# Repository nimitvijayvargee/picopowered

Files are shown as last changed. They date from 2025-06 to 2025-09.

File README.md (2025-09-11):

# picopowered
A simple microcontroller built around the RP2040.

# Changelog (V3)
- Redesigned board layout
- Doubled headers
- Dip switches and SD card slot connected to GP13-15 and GP16-19+29 respectively
- Better power system and circuit design

# Changelog (V2)
- Replaced 2020 Neopixel with more available 5050 footprint.
- Fixed seperation between 1v1 and 3v3 power planes.
- Better positioning and tracing of the components to improve overall signal integrity.
- Added a regular LED to keep it somewhat compatible with regular Pico SDK Code.
- Modified USB C port to be THT Mounted rather than completely SMD.
- Moved GPIO 29 from VSYS Sense to an exposed pad on the bottom side of the PCB.

# Featureset
| **Stat** | **Raspberry Pi Pico 1** | **Picopowered V1-RP2040** |
|---|---|---|
| Flash | 2MB | 16MB |
| Reset Button | No | Yes |
| LED | Yes (1 Color) | Yes (RGB Neopixel) |
| User GPIO Button | No | Yes |
| USB Type | Micro-B | C |

# Disadvantages
- Linear regulator requuires minimum of 3.3 Volts, unlike Pico's buck boost converter which can be powered by 1.8 Volts.
- ~~No ADC_VREF (connected to GND instead) because the power by linear regulator is filtered already.~~ ADC VREF now works with picopowered V2 and V3
- No Power Mode selection (stems from power supply used)

Most of the disadvantages occur only due to the Pico's superior power supply system, but the system on the PicoPowered board is more filtered and smooth.

# BOM
| **Part** | **Cost (USD)** |
|---|---|
| PCB + Assembly | 120 |
| Solder Wire | 3 |
| Headers | 3 |

For parts specific BOM, check picopowered.csv in /Production/

# Gallery
## V3 (Latest)
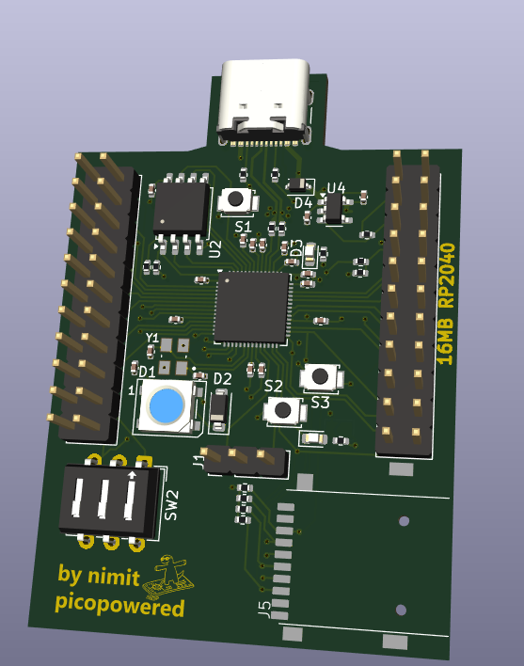
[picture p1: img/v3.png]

## V2
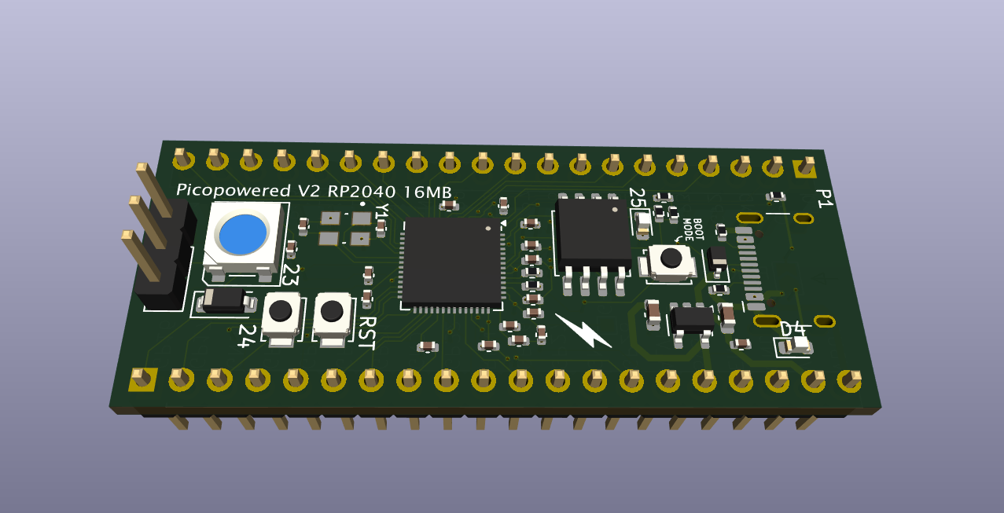
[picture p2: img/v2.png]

## V1
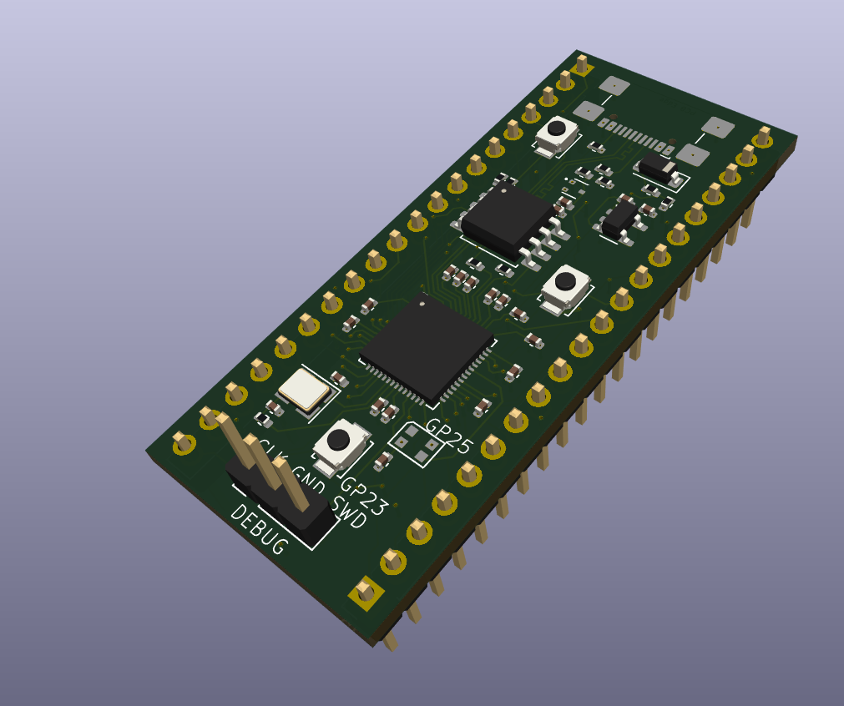
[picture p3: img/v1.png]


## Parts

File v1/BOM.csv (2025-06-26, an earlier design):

Part | Cost (USD)
PCB + Assembly | 120
Solder Wire | 3
Headers | 3
Total | 3

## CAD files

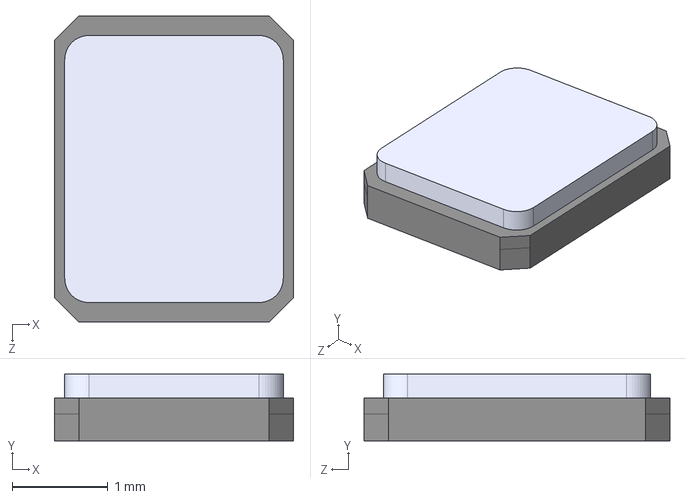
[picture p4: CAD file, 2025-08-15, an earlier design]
v2/kicad-lib/ABM8-272-T3.step
2.50 x 0.7 x 3.20 mm

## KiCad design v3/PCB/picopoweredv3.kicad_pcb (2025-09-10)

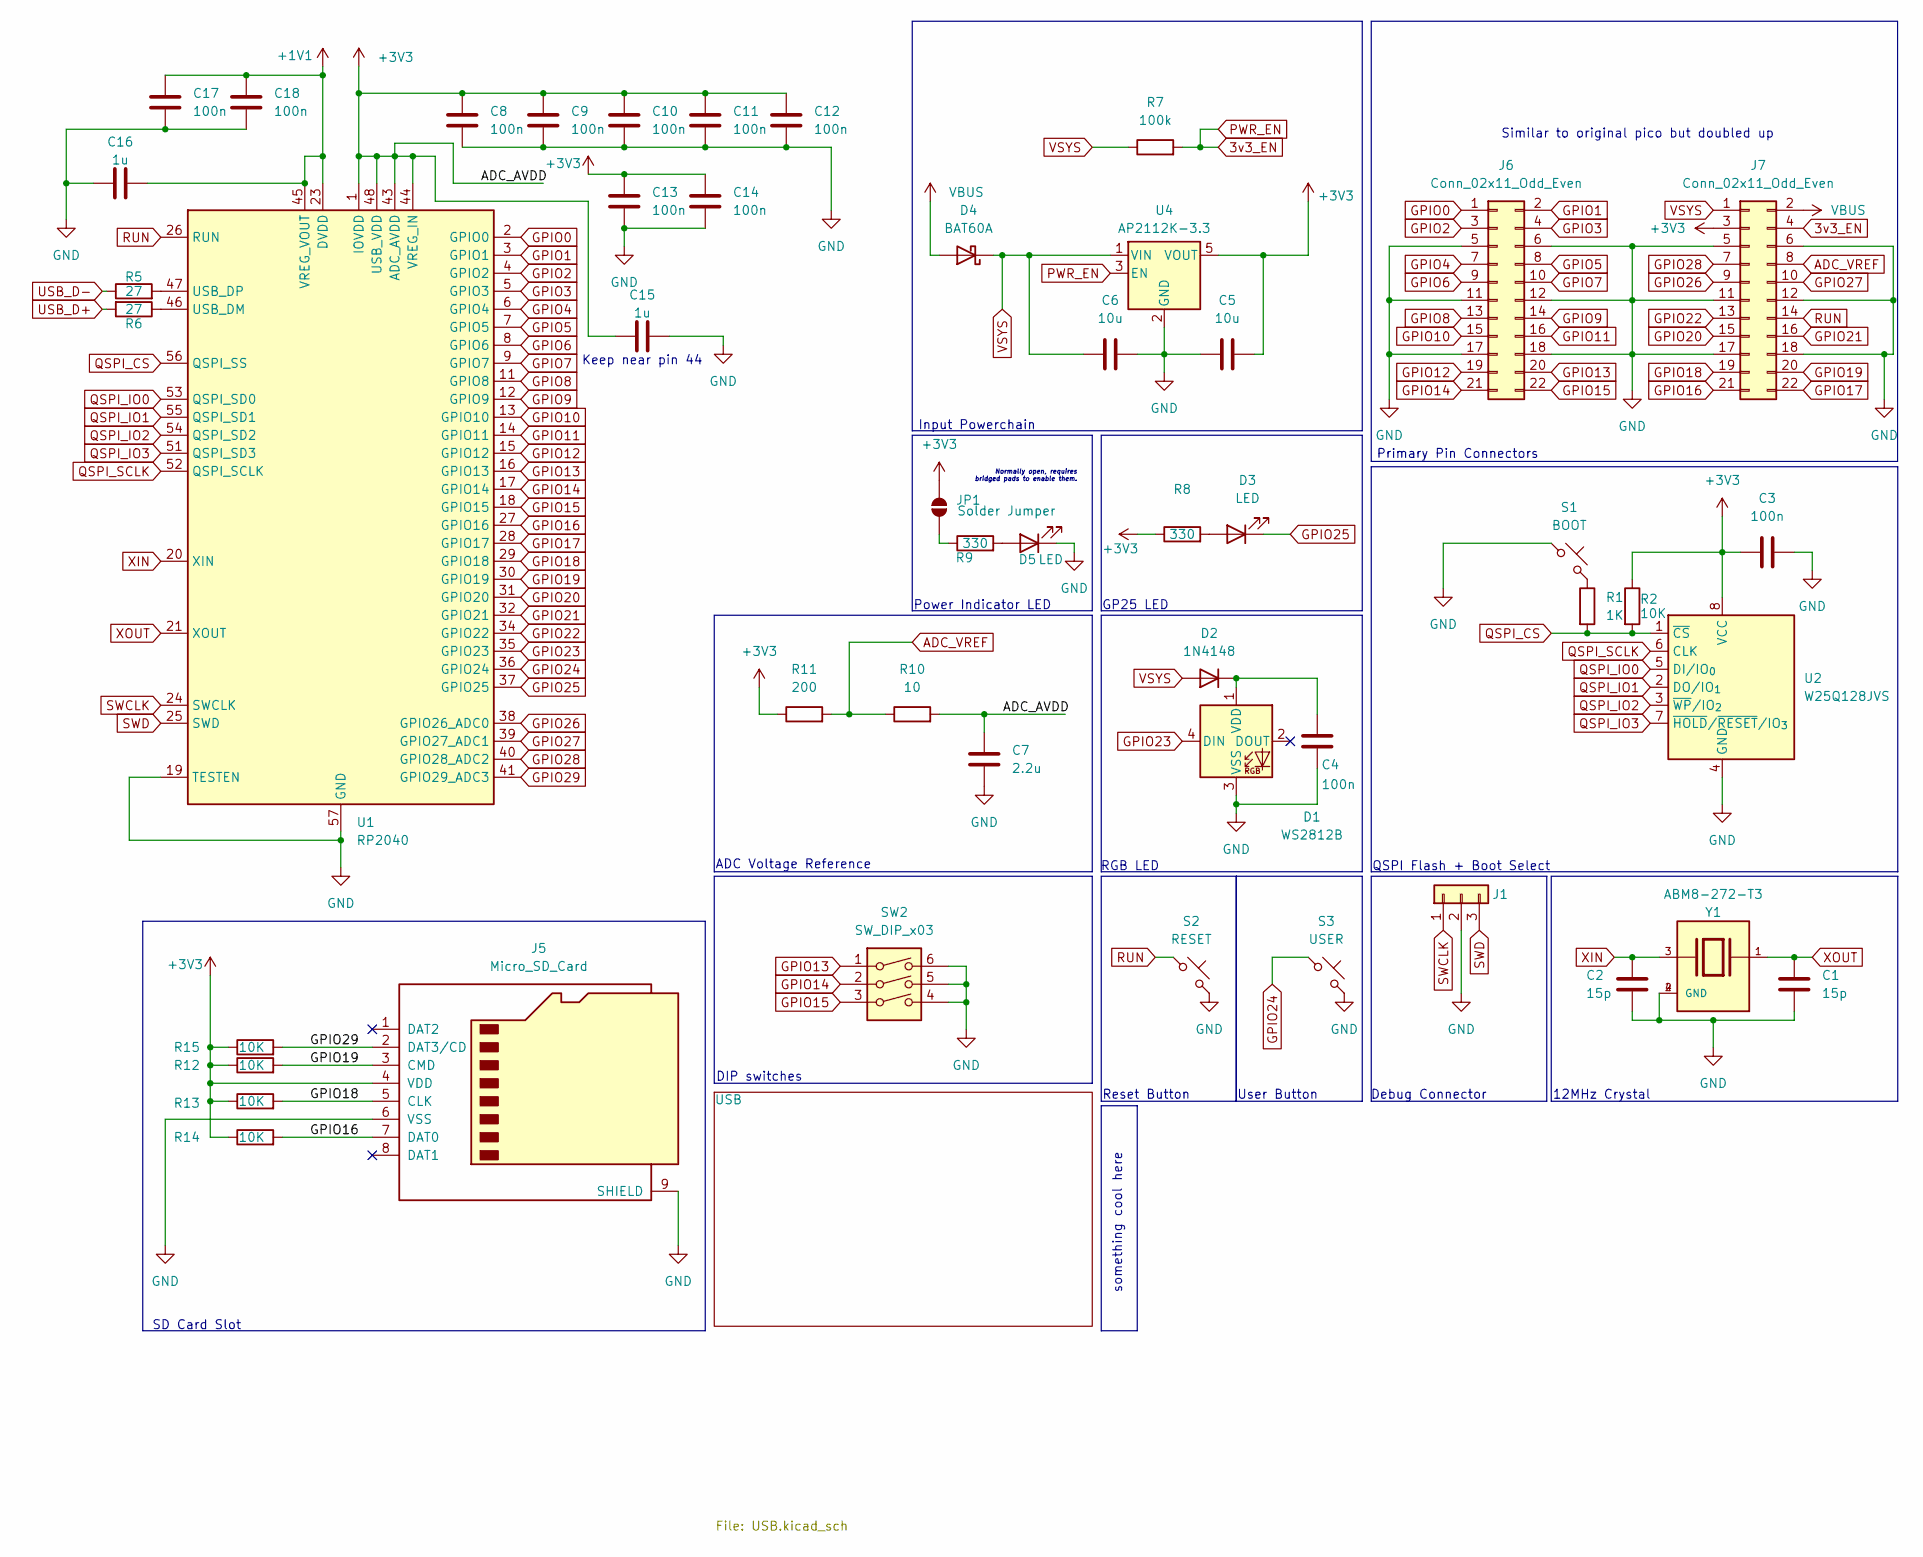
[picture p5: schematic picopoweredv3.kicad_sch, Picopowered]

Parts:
C1, C2: 15p; C_0402_1005Metric
C3, C4, C8, C9, C10, C11, C12, C13, C14, C17, C18: 100n; C_0402_1005Metric
C5, C6: 10u; C_0402_1005Metric
C7: 2.2u; C_0402_1005Metric
C15, C16: 1u; C_0402_1005Metric
D1: WS2812B; LED_WS2812B_PLCC4_5.0x5.0mm_P3.2mm
D2: 1N4148; D_SOD-123
D3, D5: LED; LED_0603_1608Metric
D4: BAT60A; D_SOD-323
J1: Conn_01x03; PinHeader_1x03_P2.54mm_Vertical
J5: Micro_SD_Card; Micro_SD_READER
J6, J7: Conn_02x11_Odd_Even; PinHeader_2x11_P2.54mm_Vertical
JP1: Solder Jumper; SolderJumper-2_P1.3mm_Open_TrianglePad1.0x1.5mm
R1: 1K; R_0402_1005Metric
R2, R12, R13, R14, R15: 10K; R_0402_1005Metric
R5, R6: 27; R_0402_1005Metric
R7: 100k; R_0402_1005Metric
R8, R9: 330; R_0402_1005Metric
R10: 10; R_0402_1005Metric
R11: 200; R_0402_1005Metric
S1: BOOT; SW_SPST_B3U-1000P
S2: RESET; SW_SPST_B3U-1000P
S3: USER; SW_SPST_B3U-1000P
SW2: SW_DIP_x03; SW_DIP_SPSTx03_Slide_6.7x9.18mm_W7.62mm_P2.54mm_LowProfile
U1: RP2040; QFN-56-1EP_7x7mm_P0.4mm_EP3.2x3.2mm
U2: W25Q128JVS; SOIC-8_5.3x5.3mm_P1.27mm
U4: AP2112K-3.3; SOT-23-5
Y1: ABM8-272-T3; XTAL_ABM8-272-T3; PARTREV 07-29-20

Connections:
3v3_EN: J7.4, R7.2, U4.3 (EN)
+1V1: C16.1, C17.1, C18.1, U1.23 (DVDD), U1.45 (VREG_VOUT), U1.50 (DVDD)
+3V3: C3.1, C5.1, C7.1, C8.1, C9.1, C10.1, C11.1, C12.1, C13.1, C14.1, C15.1, J5.4 (VDD), J7.3, JP1.2 (B), R2.1, R8.1, R10.2, R11.1, R12.1, R13.1, R14.1, R15.1, U1.1 (IOVDD), U1.10 (IOVDD), U1.22 (IOVDD), U1.33 (IOVDD), U1.42 (IOVDD), U1.43 (ADC_AVDD), U1.44 (VREG_IN), U1.48 (USB_VDD), U1.49 (IOVDD), U2.8 (VCC), U4.5 (VOUT)
ADC_VREF: J7.8, R10.1, R11.2
GND: C1.2, C2.2, C3.2, C4.1, C5.2, C6.2, C7.2, C8.2, C9.2, C10.2, C11.2, C12.2, C13.2, C14.2, C15.2, C16.2, C17.2, C18.2, D1.3 (VSS), D5.1 (K), J1.2, J5.6 (VSS), J5.9 (SHIELD), J6.5, J6.6, J6.11, J6.12, J6.17, J6.18, J7.5, J7.6, J7.11, J7.12, J7.17, J7.18, S1.1, S2.2, S3.2, SW2.4, SW2.5, SW2.6, U1.19 (TESTEN), U1.57 (GND), U2.4 (GND), U4.2 (GND), Y1.2 (GND), Y1.4 (GND); also elsewhere on the board
GPIO0: J6.1, U1.2 (GPIO0)
GPIO1: J6.2, U1.3 (GPIO1)
GPIO2: J6.3, U1.4 (GPIO2)
GPIO3: J6.4, U1.5 (GPIO3)
GPIO4: J6.7, U1.6 (GPIO4)
GPIO5: J6.8, U1.7 (GPIO5)
GPIO6: J6.9, U1.8 (GPIO6)
GPIO7: J6.10, U1.9 (GPIO7)
GPIO8: J6.13, U1.11 (GPIO8)
GPIO9: J6.14, U1.12 (GPIO9)
GPIO10: J6.15, U1.13 (GPIO10)
GPIO11: J6.16, U1.14 (GPIO11)
GPIO12: J6.19, U1.15 (GPIO12)
GPIO13: J6.20, SW2.1, U1.16 (GPIO13)
GPIO14: J6.21, SW2.2, U1.17 (GPIO14)
GPIO15: J6.22, SW2.3, U1.18 (GPIO15)
GPIO16: J5.7 (DAT0), J7.21, R14.2, U1.27 (GPIO16)
GPIO17: J7.22, U1.28 (GPIO17)
GPIO18: J5.5 (CLK), J7.19, R13.2, U1.29 (GPIO18)
GPIO19: J5.3 (CMD), J7.20, R12.2, U1.30 (GPIO19)
GPIO20: J7.15, U1.31 (GPIO20)
GPIO21: J7.16, U1.32 (GPIO21)
GPIO22: J7.13, U1.34 (GPIO22)
GPIO23: D1.4 (DIN), U1.35 (GPIO23)
GPIO24: S3.1, U1.36 (GPIO24)
GPIO25: D3.1 (K), U1.37 (GPIO25)
GPIO26: J7.9, U1.38 (GPIO26_ADC0)
GPIO27: J7.10, U1.39 (GPIO27_ADC1)
GPIO28: J7.7, U1.40 (GPIO28_ADC2)
GPIO29: J5.2 (DAT3/CD), R15.2, U1.41 (GPIO29_ADC3)
unnamed: C4.2, D1.1 (VDD), D2.1 (K)
unnamed: D3.2 (A), R8.2
unnamed: D5.2 (A), R9.2
unnamed: JP1.1 (A), R9.1
unnamed: R1.1, S1.2
unnamed: R6.1, U1.46 (USB_DM)
unnamed: R5.2, U1.47 (USB_DP)
QSPI_CS: R1.2, R2.2, U1.56 (QSPI_SS), U2.1 (~CS)
QSPI_IO0: U1.53 (QSPI_SD0), U2.5 (DI/IO_{0})
QSPI_IO1: U1.55 (QSPI_SD1), U2.2 (DO/IO_{1})
QSPI_IO2: U1.54 (QSPI_SD2), U2.3 (~WP/IO_{2})
QSPI_IO3: U1.51 (QSPI_SD3), U2.7 (~HOLD/~RESET/IO_{3})
QSPI_SCLK: U1.52 (QSPI_SCLK), U2.6 (CLK)
RUN: J7.14, S2.1, U1.26 (RUN)
SWCLK: J1.1, U1.24 (SWCLK)
SWD: J1.3, U1.25 (SWD)
USB_D+: R6.2; also elsewhere on the board
USB_D-: R5.1; also elsewhere on the board
VBUS: D4.2 (A), J7.2; also elsewhere on the board
VSYS: C6.1, D2.2 (A), D4.1 (K), J7.1, R7.1, U4.1 (VIN)
XIN: C2.1, U1.20 (XIN), Y1.3
XOUT: C1.1, U1.21 (XOUT), Y1.1

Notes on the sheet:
Similar to original pico but doubled up
DIP switches
ADC Voltage Reference
Normally open, requires bridged pads to enable them.
GP25 LED
User Button
QSPI Flash + Boot Select
Primary Pin Connectors
something cool here
RGB LED
Input Powerchain
Debug Connector
12MHz Crystal
Keep near pin 44
SD Card Slot
Power Indicator LED
Reset Button

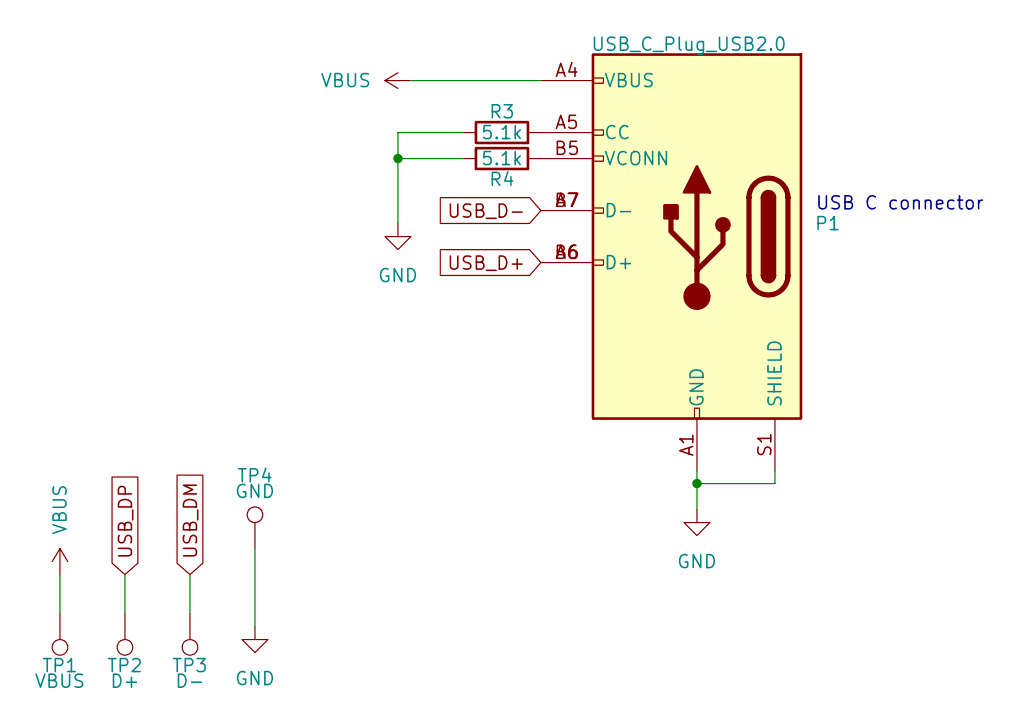
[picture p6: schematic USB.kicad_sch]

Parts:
P1: USB_C_Plug_USB2.0; USB_C_Receptacle_GCT_USB4105-xx-A_16P_TopMnt_Horizontal
R3, R4: 5.1k; R_0402_1005Metric
TP1: VBUS; TestPoint_Pad_1.0x1.0mm
TP2: D+; TestPoint_Pad_1.0x1.0mm
TP3: D-; TestPoint_Pad_1.0x1.0mm
TP4: GND; TestPoint_Pad_1.0x1.0mm

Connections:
GND: P1.A1 (GND), P1.A12 (GND), P1.B1 (GND), P1.B12 (GND), P1.S1 (SHIELD), R3.1, R4.1, TP4.1; also elsewhere on the board
unnamed: P1.A5 (CC), R3.2
unnamed: P1.B5 (VCONN), R4.2
USB_D+: P1.A6 (D+), P1.B6 (D+); also elsewhere on the board
USB_D-: P1.A7 (D-), P1.B7 (D-); also elsewhere on the board
VBUS: P1.A4 (VBUS), P1.A9 (VBUS), P1.B4 (VBUS), P1.B9 (VBUS), TP1.1; also elsewhere on the board

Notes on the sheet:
USB C connector

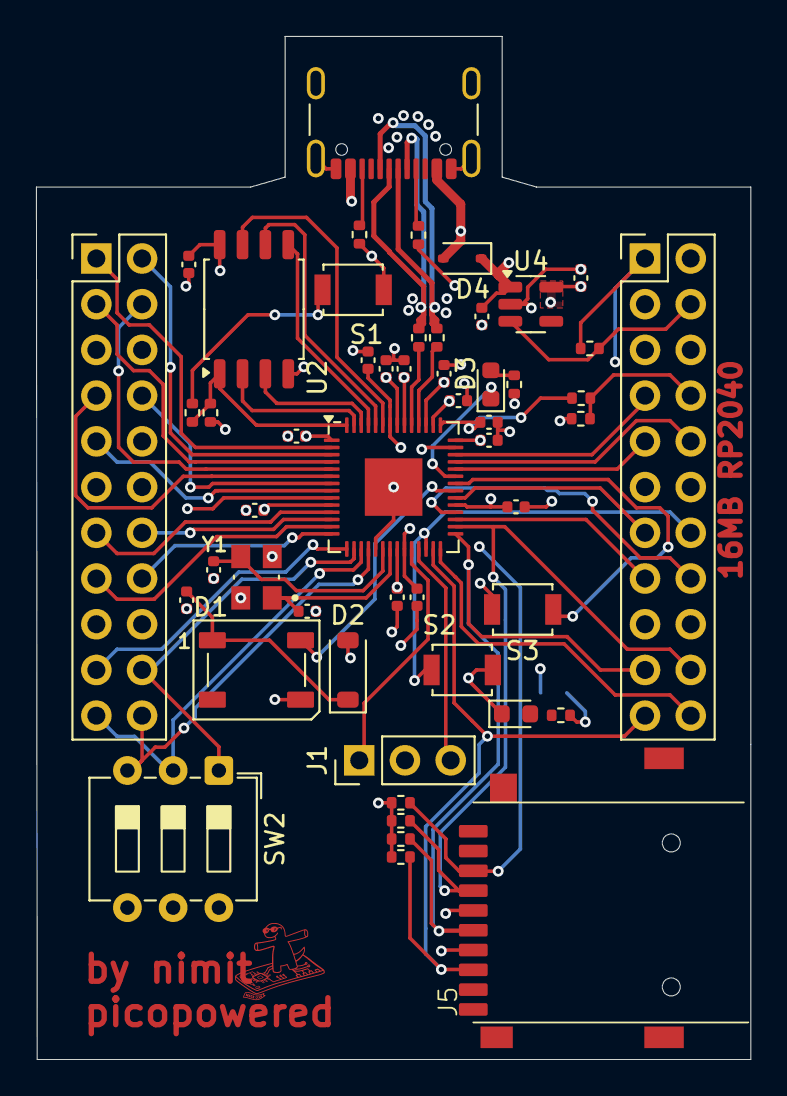
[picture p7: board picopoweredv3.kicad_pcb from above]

Board: 4 copper layers, 39.7 x 56.8 mm, 52 parts (1 on the bottom side), 59 nets.

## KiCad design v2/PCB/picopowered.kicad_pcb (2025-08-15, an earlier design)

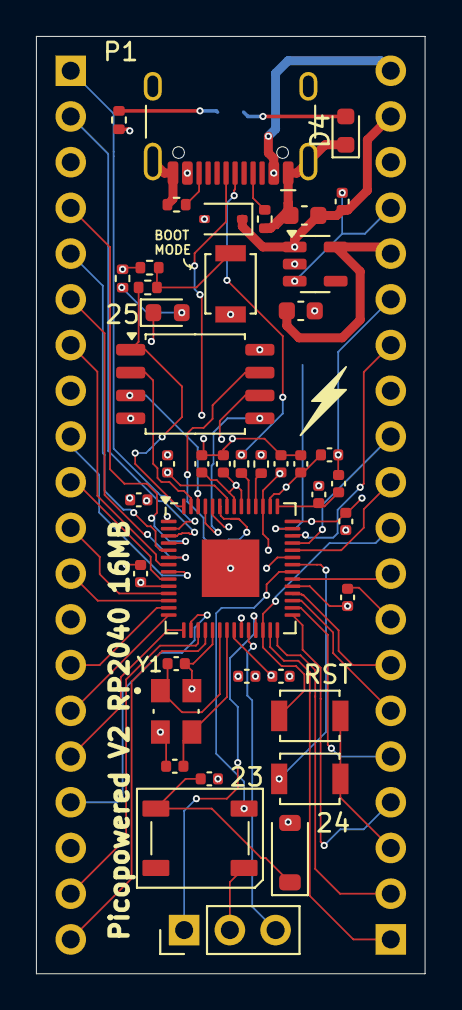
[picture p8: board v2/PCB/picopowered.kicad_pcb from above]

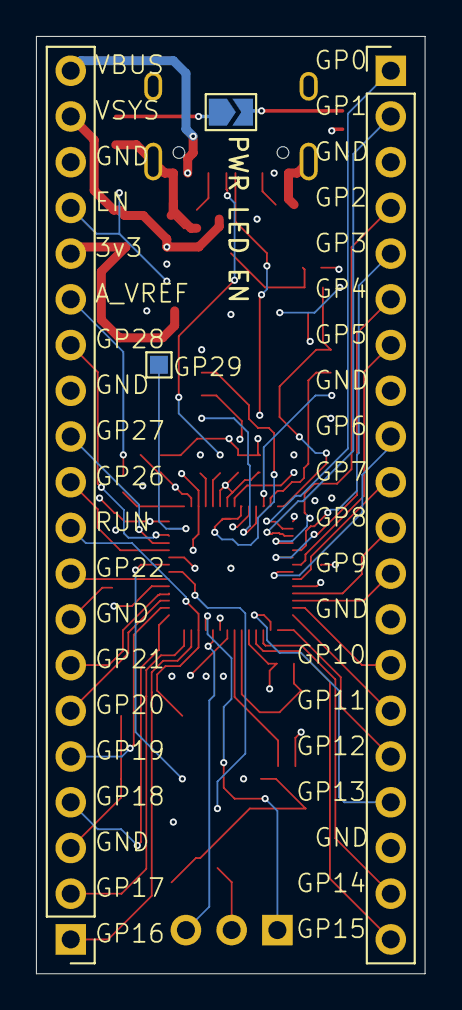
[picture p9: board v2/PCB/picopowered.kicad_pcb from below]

Board: 4 copper layers, 21.6 x 52.1 mm, 46 parts (4 on the bottom side), 60 nets.

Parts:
24: USER_BUTTON; SW_SPST_B3U-1000P
25: LED; LED_0603_1608Metric
BOOT: BOOT_SELECT; SW_SPST_B3U-1000P
C1, C2: 15p; C_0402_1005Metric
C3, C4, C5, C6, C7, C8, C9, C10, C10#2, C13: 100n; C_0402_1005Metric
C11, C12, C16: 2.2u; C_0402_1005Metric
C14: 10u; C_0603_1608Metric
C15: 22u; C_0603_1608Metric
D1: WS2812B; LED_WS2812B_PLCC4_5.0x5.0mm_P3.2mm
D2: 1N4148; D_SOD-123
D4: LED; LED_0603_1608Metric
D5: BAT60A; D_SOD-323
J1: Conn_01x03; PinHeader_1x03_P2.54mm_Vertical
J2, J3: Conn_01x20; PinHeader_1x20_P2.54mm_Vertical
P1: USB_C_Plug_USB2.0; USB_C_Receptacle_HCTL_HC-TYPE-C-16P-01A
PWR LED EN: SolderJumper_2_Open; SolderJumper-2_P1.3mm_Open_TrianglePad1.0x1.5mm
Picopowered V2 RP2040 16MB: RP2040; QFN-56-1EP_7x7mm_P0.4mm_EP3.2x3.2mm
R1, R2: 27; R_0402_1005Metric
R3: 1k; R_0402_1005Metric
R4: 10k; R_0402_1005Metric
R5, R6: 5.1k; R_0402_1005Metric
R7, R8: 330; R_0402_1005Metric
R9: 10; C_0402_1005Metric
R10: 200; C_0402_1005Metric
R11: 100K; C_0402_1005Metric
RST: Keyswitch; SW_SPST_B3U-1000P
TP1: GP29; TestPoint_Pad_1.0x1.0mm
U2: W25Q128JVS; SOIC-8_5.3x5.3mm_P1.27mm
U4: AP2112K-3.3; SOT-23-5
Y1: ABM8-272-T3; XTAL_ABM8-272-T3

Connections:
3v3_EN: J3.17, R11.1, U4.3 (EN)
+1V1: C3.1, C4.1, C12.1, Picopowered V2 RP2040 16MB.23 (DVDD), Picopowered V2 RP2040 16MB.45 (VREG_VOUT), Picopowered V2 RP2040 16MB.50 (DVDD)
+3V3: C5.1, C6.1, C7.1, C8.1, C9.1, C10.1, C10#2.1, C11.1, C15.2, J3.16, Picopowered V2 RP2040 16MB.1 (IOVDD), Picopowered V2 RP2040 16MB.10 (IOVDD), Picopowered V2 RP2040 16MB.22 (IOVDD), Picopowered V2 RP2040 16MB.33 (IOVDD), Picopowered V2 RP2040 16MB.42 (IOVDD), Picopowered V2 RP2040 16MB.44 (VREG_IN), Picopowered V2 RP2040 16MB.48 (USB_VDD), Picopowered V2 RP2040 16MB.49 (IOVDD), R4.2, R7.2, R8.2, R10.1, U2.8 (VCC), U4.5 (VOUT)
ADC_AVDD: C16.1, Picopowered V2 RP2040 16MB.43 (ADC_AVDD), R9.2
ADC_VREF: J3.15, R9.1, R10.2
GND: 24.2, BOOT.1, C1.1, C2.1, C3.2, C4.2, C5.2, C6.2, C7.2, C8.2, C9.2, C10.2, C10#2.2, C11.2, C12.2, C13.2, C14.1, C15.1, C16.2, D1.3 (VSS), D4.1 (K), J1.2, J2.3, J2.8, J2.13, J2.18, J3.3, J3.8, J3.13, J3.18, P1.A1 (GND), P1.A12 (GND), P1.B1 (GND), P1.B12 (GND), P1.S1 (SHIELD), Picopowered V2 RP2040 16MB.19 (TESTEN), Picopowered V2 RP2040 16MB.57 (GND), R5.2, R6.2, RST.2, U2.4 (GND), U4.2 (GND), Y1.2 (GND), Y1.4 (GND)
GPIO0: J2.1, Picopowered V2 RP2040 16MB.2 (GPIO0)
GPIO1: J2.2, Picopowered V2 RP2040 16MB.3 (GPIO1)
GPIO2: J2.4, Picopowered V2 RP2040 16MB.4 (GPIO2)
GPIO3: J2.5, Picopowered V2 RP2040 16MB.5 (GPIO3)
GPIO4: J2.6, Picopowered V2 RP2040 16MB.6 (GPIO4)
GPIO5: J2.7, Picopowered V2 RP2040 16MB.7 (GPIO5)
GPIO6: J2.9, Picopowered V2 RP2040 16MB.8 (GPIO6)
GPIO7: J2.10, Picopowered V2 RP2040 16MB.9 (GPIO7)
GPIO8: J2.11, Picopowered V2 RP2040 16MB.11 (GPIO8)
GPIO9: J2.12, Picopowered V2 RP2040 16MB.12 (GPIO9)
GPIO10: J2.14, Picopowered V2 RP2040 16MB.13 (GPIO10)
GPIO11: J2.15, Picopowered V2 RP2040 16MB.14 (GPIO11)
GPIO12: J2.16, Picopowered V2 RP2040 16MB.15 (GPIO12)
GPIO13: J2.17, Picopowered V2 RP2040 16MB.16 (GPIO13)
GPIO14: J2.19, Picopowered V2 RP2040 16MB.17 (GPIO14)
GPIO15: J2.20, Picopowered V2 RP2040 16MB.18 (GPIO15)
GPIO16: J3.1, Picopowered V2 RP2040 16MB.27 (GPIO16)
GPIO17: J3.2, Picopowered V2 RP2040 16MB.28 (GPIO17)
GPIO18: J3.4, Picopowered V2 RP2040 16MB.29 (GPIO18)
GPIO19: J3.5, Picopowered V2 RP2040 16MB.30 (GPIO19)
GPIO20: J3.6, Picopowered V2 RP2040 16MB.31 (GPIO20)
GPIO21: J3.7, Picopowered V2 RP2040 16MB.32 (GPIO21)
GPIO22: J3.9, Picopowered V2 RP2040 16MB.34 (GPIO22)
GPIO23: D1.4 (DIN), Picopowered V2 RP2040 16MB.35 (GPIO23)
GPIO24: 24.1, Picopowered V2 RP2040 16MB.36 (GPIO24)
GPIO25: 25.1 (K), Picopowered V2 RP2040 16MB.37 (GPIO25)
GPIO26: J3.11, Picopowered V2 RP2040 16MB.38 (GPIO26_ADC0)
GPIO27: J3.12, Picopowered V2 RP2040 16MB.39 (GPIO27_ADC1)
GPIO28: J3.14, Picopowered V2 RP2040 16MB.40 (GPIO28_ADC2)
GPIO29: Picopowered V2 RP2040 16MB.41 (GPIO29_ADC3), TP1.1
unnamed: C13.1, D1.1 (VDD), D2.1 (K)
unnamed: 25.2 (A), R7.1
unnamed: D4.2 (A), PWR LED EN.1 (A)
unnamed: J1.1, Picopowered V2 RP2040 16MB.25 (SWD)
unnamed: J1.3, Picopowered V2 RP2040 16MB.24 (SWCLK)
unnamed: PWR LED EN.2 (B), R8.1
unnamed: P1.A5 (CC), R5.1
unnamed: P1.B5 (VCONN), R6.1
unnamed: BOOT.2, R3.1, R4.1
unnamed: Picopowered V2 RP2040 16MB.46 (USB_DM), R2.2
unnamed: Picopowered V2 RP2040 16MB.47 (USB_DP), R1.2
unnamed: C1.2, Picopowered V2 RP2040 16MB.20 (XIN), Y1.1
unnamed: C2.2, Picopowered V2 RP2040 16MB.21 (XOUT), Y1.3
QSPI_SCLK: Picopowered V2 RP2040 16MB.52 (QSPI_SCLK), U2.6 (CLK)
QSPI_SD0: Picopowered V2 RP2040 16MB.53 (QSPI_SD0), U2.5 (DI/IO_{0})
QSPI_SD1: Picopowered V2 RP2040 16MB.55 (QSPI_SD1), U2.2 (DO/IO_{1})
QSPI_SD2: Picopowered V2 RP2040 16MB.54 (QSPI_SD2), U2.3 (~WP/IO_{2})
QSPI_SD3: Picopowered V2 RP2040 16MB.51 (QSPI_SD3), U2.7 (~HOLD/~RESET/IO_{3})
QSPI_SS: Picopowered V2 RP2040 16MB.56 (QSPI_SS), R3.2, U2.1 (~CS)
RUN: J3.10, Picopowered V2 RP2040 16MB.26 (RUN), RST.1
USB_D+: P1.A6 (D+), R1.1
USB_D-: P1.A7 (D-), R2.1
VBUS: D5.2 (A), J3.20, P1.A4 (VBUS), P1.A9 (VBUS), P1.B4 (VBUS), P1.B9 (VBUS)
VSYS: C14.2, D2.2 (A), D5.1 (K), J3.19, R11.2, U4.1 (VIN)

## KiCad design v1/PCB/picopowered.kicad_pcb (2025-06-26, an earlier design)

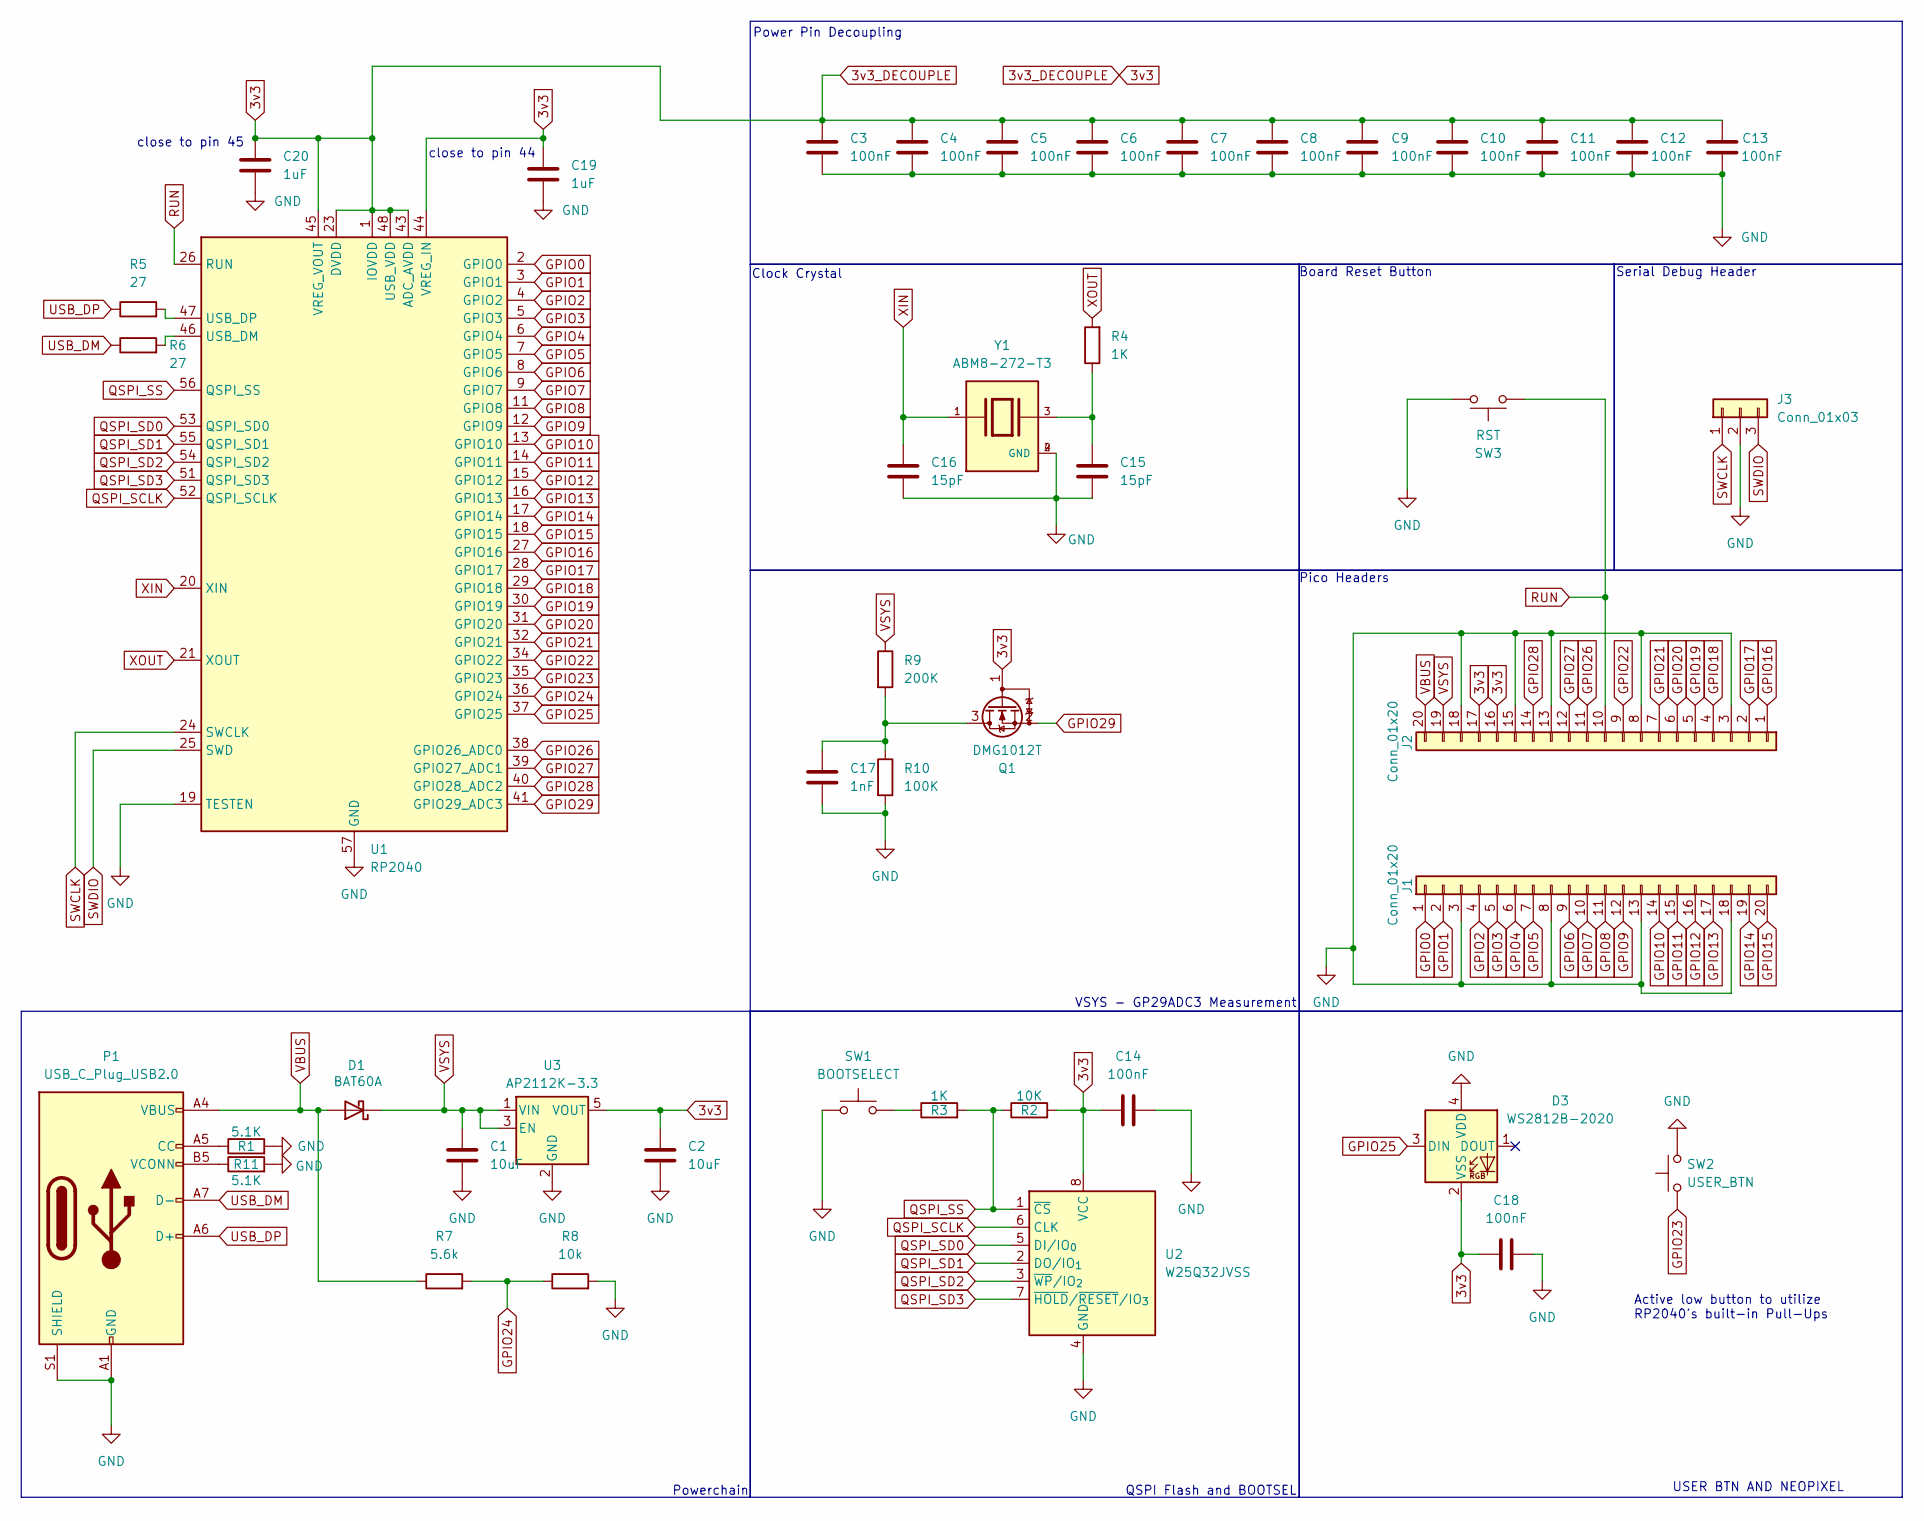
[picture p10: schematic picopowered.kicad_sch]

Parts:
C1, C2: 10uF; C_0402_1005Metric
C3, C4, C5, C6, C7, C8, C9, C10, C11, C12, C13, C14, C18: 100nF; C_0402_1005Metric
C15, C16: 15pF; C_0402_1005Metric
C17: 1nF; C_0402_1005Metric
C19, C20: 1uF; C_0402_1005Metric
D1: BAT60A; D_SOD-123
D3: WS2812B-2020; LED_WS2812B-2020_PLCC4_2.0x2.0mm
J1, J2: Conn_01x20; PinHeader_1x20_P2.54mm_Vertical
J3: Conn_01x03; PinHeader_1x03_P2.54mm_Vertical
P1: USB_C_Plug_USB2.0; USB_C_Receptacle_GCT_USB4110
Q1: DMG1012T; SOT-523
R1, R11: 5.1K; R_0402_1005Metric
R2: 10K; R_0402_1005Metric
R3, R4: 1K; R_0402_1005Metric
R5, R6: 27; R_0402_1005Metric
R7: 5.6k; R_0402_1005Metric
R8: 10k; R_0402_1005Metric
R9: 200K; R_0402_1005Metric
R10: 100K; R_0402_1005Metric
SW1: BOOTSELECT; SW_SPST_B3U-1000P
SW2: USER_BTN; SW_SPST_B3U-1000P
SW3: RST; SW_SPST_B3U-1000P
U1: RP2040; QFN-56-1EP_7x7mm_P0.4mm_EP3.2x3.2mm
U2: W25Q32JVSS; SOIC-8_5.3x5.3mm_P1.27mm
U3: AP2112K-3.3; SOT-23-5
Y1: ABM8-272-T3; Crystal_SMD_Abracon_ABM8G-4Pin_3.2x2.5mm; PARTREV 07-29-20

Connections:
3v3: C2.1, C3.1, C4.1, C5.1, C6.1, C7.1, C8.1, C9.1, C10.1, C11.1, C12.1, C13.1, C14.1, C18.1, C19.1, C20.1, D3.2 (VSS), J2.16, J2.17, Q1.1 (G), R2.2, U1.1 (IOVDD), U1.10 (IOVDD), U1.22 (IOVDD), U1.23 (DVDD), U1.33 (IOVDD), U1.42 (IOVDD), U1.43 (ADC_AVDD), U1.44 (VREG_IN), U1.45 (VREG_VOUT), U1.48 (USB_VDD), U1.49 (IOVDD), U1.50 (DVDD), U2.8 (VCC), U3.5 (VOUT)
GND: C1.2, C2.2, C3.2, C4.2, C5.2, C6.2, C7.2, C8.2, C9.2, C10.2, C11.2, C12.2, C13.2, C14.2, C15.1, C16.1, C17.2, C18.2, C19.2, C20.2, D3.4 (VDD), J1.3, J1.8, J1.13, J1.18, J2.3, J2.8, J2.13, J2.15, J2.18, J3.2, P1.A1 (GND), P1.A12 (GND), P1.B1 (GND), P1.B12 (GND), P1.S1 (SHIELD), R1.2, R8.2, R10.2, R11.2, SW1.1, SW2.2, SW3.1, U1.19 (TESTEN), U1.57 (GND), U2.4 (GND), U3.2 (GND), Y1.2 (GND), Y1.4 (GND)
GPIO0: J1.1, U1.2 (GPIO0)
GPIO1: J1.2, U1.3 (GPIO1)
GPIO2: J1.4, U1.4 (GPIO2)
GPIO3: J1.5, U1.5 (GPIO3)
GPIO4: J1.6, U1.6 (GPIO4)
GPIO5: J1.7, U1.7 (GPIO5)
GPIO6: J1.9, U1.8 (GPIO6)
GPIO7: J1.10, U1.9 (GPIO7)
GPIO8: J1.11, U1.11 (GPIO8)
GPIO9: J1.12, U1.12 (GPIO9)
GPIO10: J1.14, U1.13 (GPIO10)
GPIO11: J1.15, U1.14 (GPIO11)
GPIO12: J1.16, U1.15 (GPIO12)
GPIO13: J1.17, U1.16 (GPIO13)
GPIO14: J1.19, U1.17 (GPIO14)
GPIO15: J1.20, U1.18 (GPIO15)
GPIO16: J2.1, U1.27 (GPIO16)
GPIO17: J2.2, U1.28 (GPIO17)
GPIO18: J2.4, U1.29 (GPIO18)
GPIO19: J2.5, U1.30 (GPIO19)
GPIO20: J2.6, U1.31 (GPIO20)
GPIO21: J2.7, U1.32 (GPIO21)
GPIO22: J2.9, U1.34 (GPIO22)
GPIO23: SW2.1, U1.35 (GPIO23)
GPIO24: R7.2, R8.1, U1.36 (GPIO24)
GPIO25: D3.3 (DIN), U1.37 (GPIO25)
GPIO26: J2.11, U1.38 (GPIO26_ADC0)
GPIO27: J2.12, U1.39 (GPIO27_ADC1)
GPIO28: J2.14, U1.40 (GPIO28_ADC2)
GPIO29: Q1.2 (S), U1.41 (GPIO29_ADC3)
unnamed: C15.2, R4.1, Y1.3
unnamed: P1.A5 (CC), R1.1
unnamed: P1.B5 (VCONN), R11.1
unnamed: C17.1, Q1.3 (D), R9.2, R10.1
unnamed: R3.1, SW1.2
unnamed: R6.2, U1.46 (USB_DM)
unnamed: R5.2, U1.47 (USB_DP)
QSPI_SCLK: U1.52 (QSPI_SCLK), U2.6 (CLK)
QSPI_SD0: U1.53 (QSPI_SD0), U2.5 (DI/IO_{0})
QSPI_SD1: U1.55 (QSPI_SD1), U2.2 (DO/IO_{1})
QSPI_SD2: U1.54 (QSPI_SD2), U2.3 (~WP/IO_{2})
QSPI_SD3: U1.51 (QSPI_SD3), U2.7 (~HOLD/~RESET/IO_{3})
QSPI_SS: R2.1, R3.2, U1.56 (QSPI_SS), U2.1 (~CS)
RUN: J2.10, SW3.2, U1.26 (RUN)
SWCLK: J3.1, U1.24 (SWCLK)
SWDIO: J3.3, U1.25 (SWD)
USB_DM: P1.A7 (D-), R6.1
USB_DP: P1.A6 (D+), R5.1
VBUS: D1.2 (A), J2.20, P1.A4 (VBUS), P1.A9 (VBUS), P1.B4 (VBUS), P1.B9 (VBUS), R7.1
VSYS: C1.1, D1.1 (K), J2.19, R9.1, U3.1 (VIN), U3.3 (EN)
XIN: C16.2, U1.20 (XIN), Y1.1
XOUT: R4.2, U1.21 (XOUT)

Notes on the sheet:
USER BTN AND NEOPIXEL
Serial Debug Header
Pico Headers
Active low button to utilize RP2040's built-in Pull-Ups
close to pin 45
Power Pin Decoupling
Board Reset Button
Powerchain
VSYS - GP29ADC3 Measurement
QSPI Flash and BOOTSEL
Clock Crystal
close to pin 44

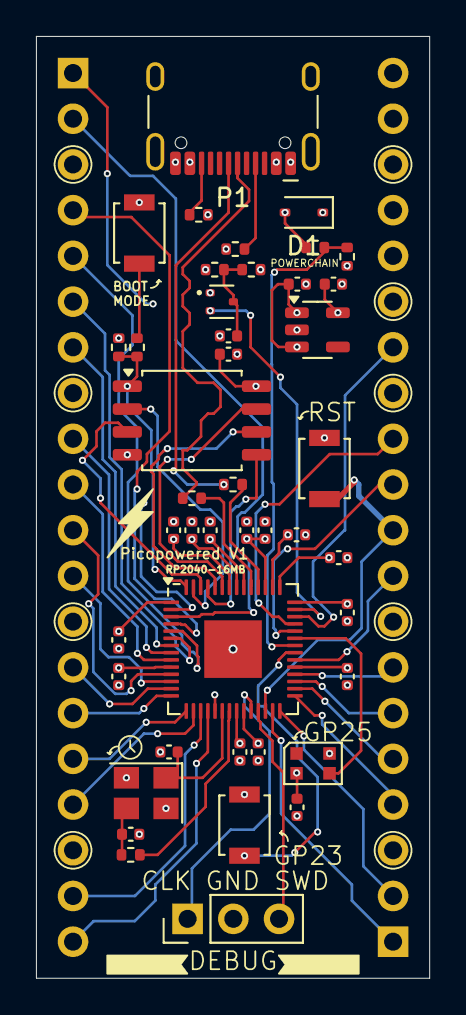
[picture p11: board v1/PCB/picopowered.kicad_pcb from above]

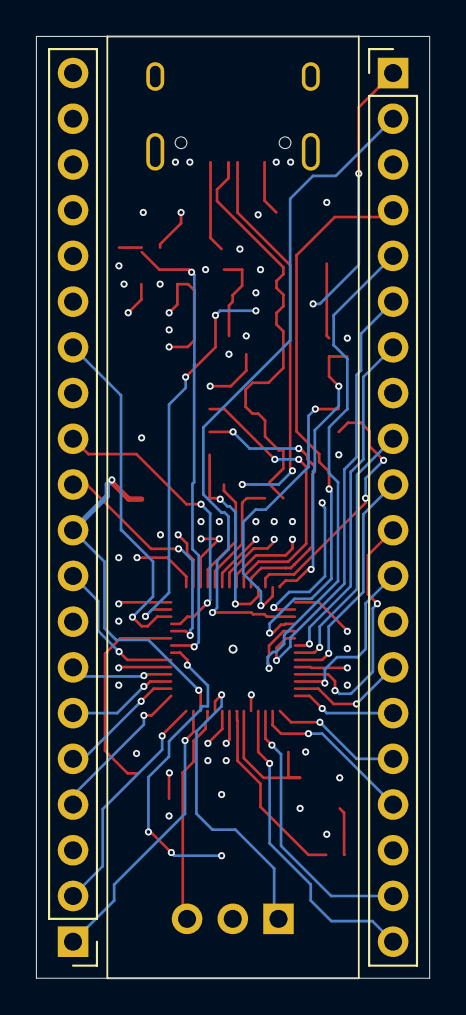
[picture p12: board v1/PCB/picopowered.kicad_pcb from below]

Board: 4 copper layers, 21.8 x 52.3 mm, 45 parts (2 on the bottom side), 54 nets.

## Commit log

2025-06-19 line breaks are a powerful tool
2025-06-25 Submission Ready
    [picopowered.csv, picopowered.kicad_pcb, picopowered.kicad_sch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]
2025-06-26 Minor Changes
    [component_bom.csv, component_positioning.csv, picopowered.kicad_pcb]
2025-06-26 Minor trace changes and updated BOM
    [BOM.csv, picopowered.csv, picopowered.kicad_pcb]
2025-08-15 Add version 2
    [ABM8-272-T3.step, BOM.csv, component_bom.csv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]
2025-09-10 Version 3!
    [USB.kicad_sch, picopoweredv3.kicad_pcb, picopoweredv3.kicad_sch]
2025-09-10 Rename PCB folder and update README
    [USB.kicad_sch, picopoweredv3.kicad_pcb, picopoweredv3.kicad_sch]
